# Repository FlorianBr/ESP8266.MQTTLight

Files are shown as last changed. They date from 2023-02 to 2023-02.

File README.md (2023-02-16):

# ESP8266 MQTT-Light

## Whats this?

I wanted some sort of RGB light to signal all sort of things: New emails, high server load... stuff like that. So looked through the electronics stuff I had flying around to see what I can use for this kind of job.

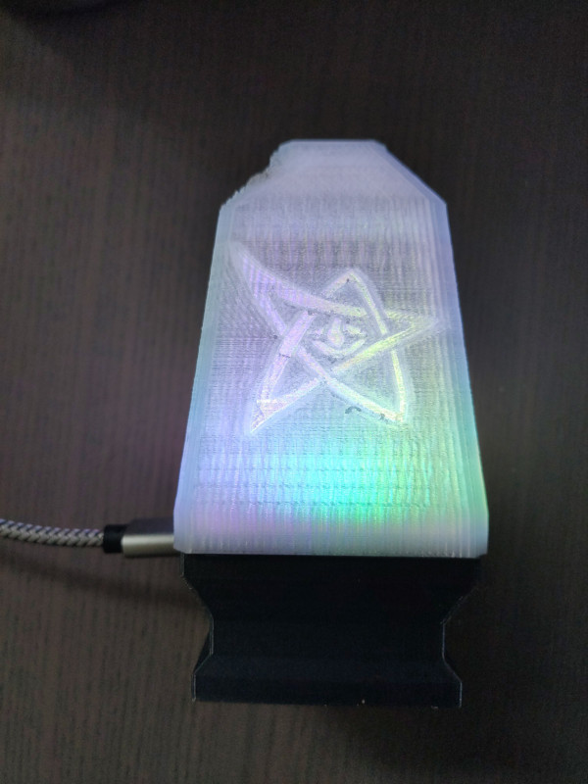
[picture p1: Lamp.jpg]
Lamp


## Components

### Electronics

- A old ESP8266 board. More than enough for that simple task
- A Adafruit NeoPixel Ring with 12 LEDs

I also had a few unused ESP-01S, but they need 3,3V and I would have needed a converter from 5V to 3.3V plus a USB converter for programming. The "big" ESP8266 Devkit has integrated USB, making SW development and flashing easier and also powers everything over USB. Plus the wiring is much simpler, the LED ring can be directly wired to the ESP without any additional components. Even a PCB is unnecessary.

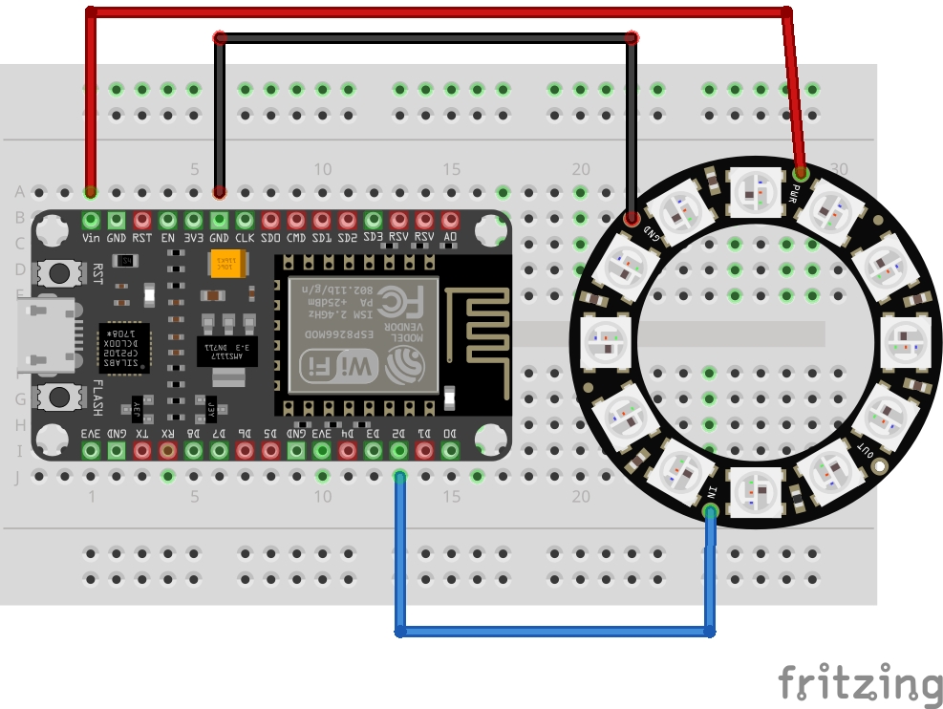
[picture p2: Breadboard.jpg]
Breadboard


### Mechanics

Based on [dutchmoguls Elder Sign Nightlight](https://www.thingiverse.com/thing:921962).

I redesigned the base to accommodate the ESP and the LED ring

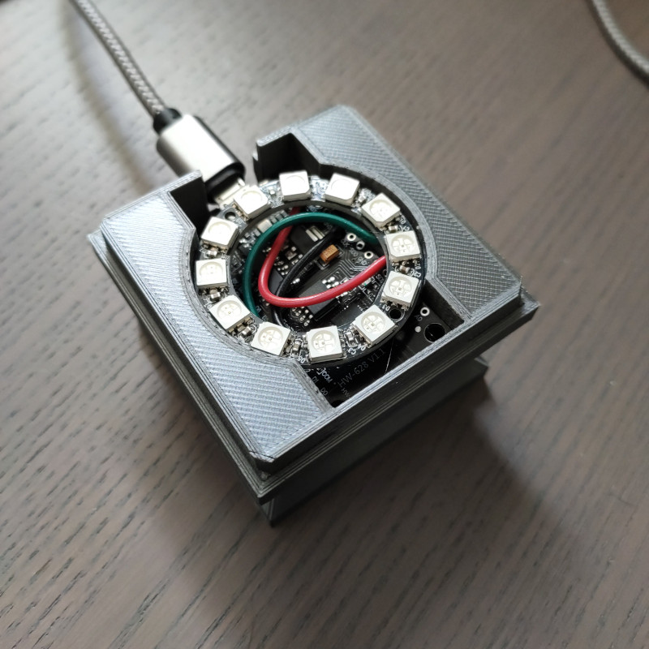
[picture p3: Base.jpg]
Base


## Libaries

- FastLED Animation Library: For controlling the LED ring
- ESP8266WiFi: For the WiFi connectivity
- PubSubClient: For MQTT messaging
- ArduinoJSON: For serialisation / deserialisation of JSON strings

## How to use

WiFi credentials (SSID and pass) are hardcoded in secrets.h. The MQTT broker address is set in the define MQTT_BROKER in LEDLamp.ino

When started, the lamp will send its status to MQTT and can receive the following commands send to the /cmd subtopic:

- Set the color 1 for effects (not always used) with { "setcolor1": [255,255,0] }
- Set the color 2 for effects (not always used) with { "setcolor2": [255,255,0] }
- Set the delay for effects to slow down or speed up: { "setdelay": 1000 }
- Set the brightness: { "setbright": 100 }
- Set the color pattern to use { "setpattern": 1 }
  - 0 .. Solid Color 1
  - 1 .. Rainbow Effect
  - 2 .. Gradient White to Color 1
  - 3 .. Gradient Black to Color 1
  - 4 .. Gradient from Color 1 to Color 2
  - 5 .. Single Dot with Color 1
  - 6 .. Smoothed Dot with Color 1
- Set the color effect with { "seteffect": 1 }
  - 0 .. No effect
  - 1 .. Breathe
  - 2 .. Breathe with pause
  - 3 .. Rotate
  - 4 .. Glitter
  - 5 .. Randomizer (fire-ish effect)

## Todos

- Print a better transparent lid, currently a draft print

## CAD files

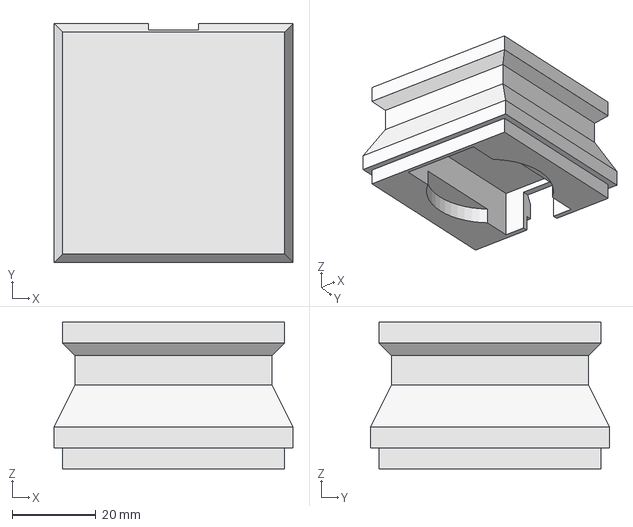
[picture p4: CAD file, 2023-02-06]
3D-Parts/ElderSignBase_v3.FCStd
57.0 x 57.0 x 35.0 mm

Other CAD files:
3D-Parts/ElderSignBase_v3.stl

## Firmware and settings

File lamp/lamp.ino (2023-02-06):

#include <ESP8266WiFi.h>                // ESP8266 WiFi
#include <PubSubClient.h>               // MQTT
#include <FastLED.h>                    // FastLED library
#include <ArduinoJson.h>                // JSON deserialisation

#include "secrets.h"                    // WiFi Secrets (SSID and Password)

/****************************** Config */

#define MQTT_BROKER   "192.168.178.19"  // Hostname/IP of the broker
#define MQTT_PORT     1883              // Port of the Broker
#define MQTT_BASE     "ESPLIGHT"        // MQTT Basename
#define MAX_TOPICLEN  100               // Max. length of topic string
#define MAX_MSGLEN    100               // Max. length of message string
#define MAX_HNLEN     100               // Max. length of the hostname
#define NUM_LEDS      12                // Number of LEDs in the LED-Ring
#define LED_DATAPIN   4                 // DOUT to LED Ring (GPIO4 = D2)

#define LOOPTIME      1000              // Statistic updateloop in ms

/****************************** Globals */

typedef enum  {
  PAT_SOLID,        // All LEDs with Color 1
  PAT_RAINBOW,      // Rainbow
  PAT_WHITEGRAD,    // Color 1 to white gradient
  PAT_BLACKGRAD,    // Color 1 to black gradient
  PAT_COLGRAD,      // Color 1 to Color 2 gradient
  PAT_DOT,          // Single dot in Color 1
  PAT_SMOOTHDOT     // Single dot in Color 1 smoothed
} tyPatterns;

typedef enum  {
  EFF_SOLID,        // Simple, solid 
  EFF_BREATHE1,     // Sine-wave brightness
  EFF_BREATHE2,     // Sine-wave brightness with pause
  EFF_ROTATE,       // Rotate pattern
  EFF_GLITTER,      // Add glitter to the pattern
  EFF_RANDOM        // Randomize brightness
} tyEffects;

WiFiClient    m_espClient;              // The WiFi object
PubSubClient  m_Client(m_espClient);    // The MQTT object on WiFi
 
char          m_cBaseTopic[100] = "";   // Systems base topic

CRGB          m_Leds[NUM_LEDS];         // The LEDs
CRGB          m_Color1 = CRGB::Red;     // Color 1
CRGB          m_Color2 = CRGB::Green;   // Color 2
tyPatterns    m_Pattern = PAT_SOLID;    // Current LED Mode
tyEffects     m_Effect = EFF_SOLID;     // Current Effect Mode
uint16_t      m_delay=50;               // Loop-Delay
bool          m_FullRefresh = true;     // Trigger a full refresh after changing pattern, effect, etc

/****************************** The Functions */

/**
 * @brief Set a new Pattern
 * 
 * @param NewPattern 
 */
void SetPattern(tyPatterns NewPattern) {
  switch (m_Pattern) {
    default:
      m_Pattern = PAT_SOLID;
      // Fall through!
    case PAT_SOLID:
      fill_solid(m_Leds, NUM_LEDS, m_Color1);
      break;
    case PAT_RAINBOW:
      fill_rainbow(m_Leds, NUM_LEDS, 0, 21);
      break;
    case PAT_WHITEGRAD:
      fill_gradient_RGB(m_Leds, 0, CRGB::White, NUM_LEDS-1, m_Color1);
      break;
    case PAT_BLACKGRAD:
      fill_gradient_RGB(m_Leds, 0, CRGB::Black, NUM_LEDS-1, m_Color1);
      break;
    case PAT_COLGRAD:
      fill_gradient_RGB(m_Leds, 0, m_Color1, NUM_LEDS-1, m_Color2);
      break;
    case PAT_DOT:
      fill_solid(m_Leds, NUM_LEDS, CRGB::Black);
      m_Leds[NUM_LEDS/2] = m_Color1;
      break;
    case PAT_SMOOTHDOT:
      fill_solid(m_Leds, NUM_LEDS, CRGB::Black);
      m_Leds[NUM_LEDS/2] = m_Color1;
      blur1d(m_Leds, NUM_LEDS, 64);
      break;
  } // switch
  return;
}

/**
 * @brief The mqtt status worker
 */
void StatusWorker() {
  static unsigned long nextupdate = 0;

  // Publish status data every sec to MQTT
  if (millis() >= nextupdate) {
    nextupdate = millis() + LOOPTIME;

    char cTopic[MAX_TOPICLEN];
    char cMessage[MAX_MSGLEN];
    StaticJsonDocument<200> doc;

    doc["uptime"] = millis()/1000;
    doc["pattern"] = m_Pattern;
    doc["effect"] = m_Effect;

    doc["delay"] = m_delay;
    JsonArray data1 = doc.createNestedArray("color1");
    data1.add(m_Color1.r);
    data1.add(m_Color1.g);
    data1.add(m_Color1.b);

    JsonArray data2 = doc.createNestedArray("color2");
    data2.add(m_Color2.r);
    data2.add(m_Color2.g);
    data2.add(m_Color2.b);

    snprintf(&cTopic[0], MAX_TOPICLEN, "%s/stats", m_cBaseTopic);
    serializeJson(doc, cMessage);
    m_Client.publish(cTopic, cMessage);
  } // next update

  return;
}

/**
 * @brief The effect worker, called cyclic
 */
void EffectWorker() {
  static uint8_t effect_tick = 0;
  switch (m_Effect) {
    default:
      m_Effect = EFF_SOLID;
      // Fall through!
    case EFF_SOLID: 
      break;
    case EFF_BREATHE1:
      FastLED.setBrightness(quadwave8(effect_tick));
      effect_tick++; // Overflows!
      break;
    case EFF_BREATHE2:
      FastLED.setBrightness(quadwave8(effect_tick));
      effect_tick++; // Overflows!
      if (effect_tick == 0) FastLED.delay(1000);
      break;
    case EFF_ROTATE:
      {
        CRGB OverflowCol = m_Leds[0];
        for (int i = 0; i < NUM_LEDS-1; i++){        
          m_Leds[i]=m_Leds[i+1];
        }
        m_Leds[NUM_LEDS-1] = OverflowCol;
      }
      break;
    case EFF_GLITTER:
      {
        uint8_t RandomVal = random(0, 99);
        if (RandomVal<10) {  // 10 percent probability
          CRGB OldColor;
          uint8_t Position;

          Position = random(0, NUM_LEDS-1);
          OldColor = m_Leds[Position];
          m_Leds[Position] = CRGB::White;

          FastLED.delay(50);

          m_Leds[Position] = OldColor;
        }
      }
      break;
    case EFF_RANDOM: // Randomizer (fire effect)
      {
        // TODO Should be smoother
        for (uint8_t i=0; i<NUM_LEDS; i++) {
          uint8_t val = random(0,0xFF);
          m_Leds[i] = m_Color1;
          m_Leds[i].subtractFromRGB(val);
        }
      }
      break;
  } // switch
  return;
} // EffectWorker

/**
 * @brief Callback for received MQTT commands
 * 
 * @param topic 
 * @param payload 
 * @param length 
 */
void mqtt_callback(char* topic, byte* payload, unsigned int length) {

  // JSON deserialisation
  StaticJsonDocument<200> jsonDoc;
  DeserializationError error = deserializeJson(jsonDoc, payload);

  // Test if parsing succeeds.
  if (error) {
    return;
  }

  // Set Mode with { "setpattern": 1 }
  if (jsonDoc.containsKey("setpattern")) {
    m_Pattern = jsonDoc["setpattern"].as<tyPatterns>();
    m_FullRefresh = true;
  }

  // Set Mode with { "seteffect": 1 }
  if (jsonDoc.containsKey("seteffect")) {
    m_Effect = jsonDoc["seteffect"].as<tyEffects>();
    m_FullRefresh = true;
  }

  // Set Color 1 with { "setcolor1": [255,255,0] }
  if (jsonDoc.containsKey("setcolor1")) {
    m_Color1.r = jsonDoc["setcolor1"][0].as<int>();
    m_Color1.g = jsonDoc["setcolor1"][1].as<int>();
    m_Color1.b = jsonDoc["setcolor1"][2].as<int>();
    m_FullRefresh = true;
  }

  // Set Color 2 with { "setcolor2": [255,255,0] }
  if (jsonDoc.containsKey("setcolor2")) {
    m_Color2.r = jsonDoc["setcolor2"][0].as<int>();
    m_Color2.g = jsonDoc["setcolor2"][1].as<int>();
    m_Color2.b = jsonDoc["setcolor2"][2].as<int>();
    m_FullRefresh = true;
  }

  // Set Delay with { "setdelay": 1000 }
  if (jsonDoc.containsKey("setdelay")) {
    m_delay = jsonDoc["setdelay"].as<int>();
  }

  // Set Brightness with { "setbright": 50 }
  if (jsonDoc.containsKey("setbright")) {
    FastLED.setBrightness(jsonDoc["setbright"].as<int>());
  }

} // mqtt_callback

/**
 * @brief Reconnect to the broker if not connected. Not blocking
 */
void mqtt_reconnect() {
  if (!m_Client.connected()) {
    if (m_Client.connect("ESP8266")) {
      char cTopic[MAX_TOPICLEN];
      snprintf(&cTopic[0], MAX_TOPICLEN, "%s/cmd", m_cBaseTopic);
      m_Client.subscribe(cTopic);
    }
  }
} // mqtt_reconnect

/**
 * @brief System setup
 */
void setup() {
  // WiFi (Client only)
  WiFi.mode(WIFI_STA);

  // Generate Wifi Hostname with Basename and Chip-ID
  char cBuffer[MAX_HNLEN];
  snprintf(&cBuffer[0], MAX_HNLEN, "%s_%X", MQTT_BASE, system_get_chip_id() );
  WiFi.hostname(cBuffer);
  WiFi.begin(ssid, password);

  // Wait for WiFi connection
  // TODO: Add timeout with system reset
  while (WiFi.status() != WL_CONNECTED) {
    delay(500);
  }

  // MQTT Basename plus Chip-ID
  snprintf(&m_cBaseTopic[0], MAX_TOPICLEN, "%s_%X", MQTT_BASE, system_get_chip_id() );
  m_Client.setServer(MQTT_BROKER, MQTT_PORT);
  m_Client.setCallback(mqtt_callback);

  // FastLED Setup
  FastLED.addLeds<NEOPIXEL, LED_DATAPIN>(m_Leds, NUM_LEDS);
  FastLED.setMaxPowerInVoltsAndMilliamps(5, 500);
  fill_solid(m_Leds, NUM_LEDS, m_Color1);

  // Random Seed
  randomSeed(analogRead(0));

} // setup

/**
 * @brief Arduino system loop 
 */
void loop() {
  if (WiFi.status() == WL_CONNECTED) {
    if (!m_Client.connected()) {
      mqtt_reconnect();
    } else {
      m_Client.loop();          // MQTT client loop
      StatusWorker();           // MQTT status

      if (m_FullRefresh) {      // Update LED pattern if necessary
        SetPattern(m_Pattern);
        m_FullRefresh = false;
      }
      EffectWorker();           // Effect worker

      FastLED.delay(m_delay);   // Also triggers a .show()
    } // Client.connected
  } else {
    // TODO: If not connected, retry and/or restart system
  }
} // loop

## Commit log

2023-02-06 Added: 3D printed parts
    [ElderSignBase_v3.FCStd, ElderSignBase_v3.stl]
2023-02-06 Added: Fritzing scematic
    [Breadboard.fzz]
